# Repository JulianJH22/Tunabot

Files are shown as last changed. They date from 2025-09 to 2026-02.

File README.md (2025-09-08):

# Tunabot
Tunabot es un proyecto educativo y experimental que busca recrear el movimiento y comportamiento de los atunes en el agua.  🐟 Robot Atún: un prototipo que se desplaza en el agua simulando el movimiento natural del pez.  🐟 Sigueobjetos: un sistema que replica los bancos de atunes, siguiendo el movimiento de otros miembros..

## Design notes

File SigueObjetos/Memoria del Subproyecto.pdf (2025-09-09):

# MEMORIA DEL "SIGUEOBJETOS”

## Proyecto Tunabot

TUNABOT | 1

## Memoria del "SigueObjetos”

## 1. Introducción

El subproyecto SigueObjetos forma parte del proyecto global Tunabot, una iniciativa centrada en la divulgación científica y tecnológica en torno al comportamiento del atún, con un enfoque práctico desde la robótica educativa. El SigueObjetos surgió con el objetivo de mostrar, a través de prototipos robóticos, cómo se comportan los atunes en grupo y cómo su coordinación puede ser interpretada y replicada mediante sensores, actuadores y microcontroladores. En este contexto, el subproyecto se centra en emular la capacidad de seguimiento y reacción grupal que muestran los bancos de atunes.

## 2. Objetivo del subproyecto

El objetivo principal es desarrollar un robot capaz de detectar y seguir un objeto, simulando así el comportamiento de los atunes al moverse de forma sincronizada dentro de un banco.
El enfoque del proyecto es tanto divulgativo como formativo, permitiendo a estudiantes y público general explorar principios básicos de sensorización, programación y control robótico.

## 3. Enfoque técnico

### 3.1. Primera fase: SigueColores

La primera versión del prototipo se basó en el concepto de SigueColores. La idea era que el robot fuera capaz de:
- Detectar el color de una tarjeta mediante un sensor RGB.
- Medir la distancia hasta la tarjeta usando un sensor de ultrasonido.
- Detectar el movimiento lateral de la tarjeta mediante dos sensores IR (infrarrojos), ubicados a izquierda y derecha del robot.
- En función de esa información, el robot podría girar a izquierda o derecha o avanzar para seguir la tarjeta.
Componentes utilizados
- Placa Arduino Uno
- Dos motores DC con ruedas (movimiento)
- Sensor RGB (detección de color)
- Sensor ultrasónico HC-SR04 (medición de distancia)
- Dos sensores infrarrojos (detección de movimiento lateral)

- Chasis básico de robot con soporte para los componentes
- Batería o alimentación externa

### 3.1.1. Desarrollo del prototipo

El desarrollo se dividió en varias etapas:
1. Montaje físico del robot: Ensamblaje del chasis, motores, sensores y cableado con la placa Arduino.
2. Programación de sensores:
- Se calibró el sensor RGB para reconocer únicamente el color deseado de la tarjeta.
- Se establecieron umbrales de distancia segura con el sensor ultrasónico.
- Se configuraron los sensores IR para detectar si el objeto se desplazaba a un lado u otro.
3. Lógica de movimiento:
- Si el objeto está centrado y dentro del rango de distancia, el robot avanza.
- Si el objeto se desplaza hacia un lateral, el robot gira hacia ese lado.
- Si se pierde el objeto o se aleja demasiado, el robot se detiene.
- En cada paso se deberá confirmar que el color de la tarjeta es el deseado.
4. Pruebas y ajustes: Se realizaron pruebas en distintos entornos y condiciones de luz, adaptando parámetros para mejorar la estabilidad y precisión.

### 3.1.2. Resultados y dificultades

El robot era capaz de identificar la tarjeta y perseguirla, pero solo bajo unas condiciones lumínicas específicas que dependía tanto de la iluminación interior como del clima y la hora del día.

### 3.1.3. Conclusiones y mejoras futuras

Debido a los resultados obtenidos y a la fuerte dependencia del robot de la luz, se decidió tomar otra orientación en el proyecto y hacerlo SigueObjetos. De esta forma se elimina la dependencia de la luz, pues no habría colores que determinar y además se simplificaría significativamente, ideal para la divulgación.

### 3.2. Segunda fase: SigueObjetos

La segunda versión del prototipo se basó en el concepto de SigueObjetos. La idea era que el robot fuera capaz de:
- Medir la distancia hasta un objeto usando un sensor de ultrasonido.
- Detectar el movimiento lateral de la tarjeta mediante dos sensores ultrasonido, ubicados a izquierda y derecha del robot.
- En función de esa información, el robot podría girar a izquierda o derecha o avanzar para seguir la tarjeta.
Componentes utilizados
- Placa Arduino Uno
- Dos motores DC con ruedas (movimiento)
- Tres Sensores ultrasónicos HC-SR04 (medición de distancia)
- Chasis básico de robot con soporte para los componentes
- Batería o alimentación externa

### 3.2.1. Desarrollo del prototipo

El desarrollo se dividió en varias etapas:
5. Montaje físico del robot: Ensamblaje del chasis, motores, sensores y cableado con la placa Arduino.
6. Programación de sensores:
- Se establecieron umbrales de distancia segura con el sensor ultrasónico frontal.
- Se configuraron los sensores ultrasónicos laterales para detectar si el objeto se desplazaba a un lado u otro. Para facilitar su uso se digitalizaron (darían un 1 si la distancia era menor a la determinada en programación y 0 si era mayor).
7. Lógica de movimiento:
- Si el objeto está centrado y dentro del rango de distancia, el robot avanza.
- Si el objeto se desplaza hacia un lateral, el robot gira hacia ese lado.
- Si se pierde el objeto o se aleja demasiado, el robot se detiene.
8. Pruebas y ajustes: Se realizaron pruebas en distintos entornos, adaptando parámetros para mejorar la estabilidad y precisión.

### 3.2.2. Resultados y dificultades

El robot era capaz de perseguir el objeto sin problemas aparentes, tras pulir el código y los parámetros no hubo problemas en el desempeño del robot.

### 3.2.3. Conclusiones y mejoras futuras

Debido al éxito en el desarrollo de este robot se decidió hacerlo más estético diseñando una PCB (Printed Circuit Board) para simplificar las conexiones y un carenado en forma de atún.

## 4. Anexo de Imágenes

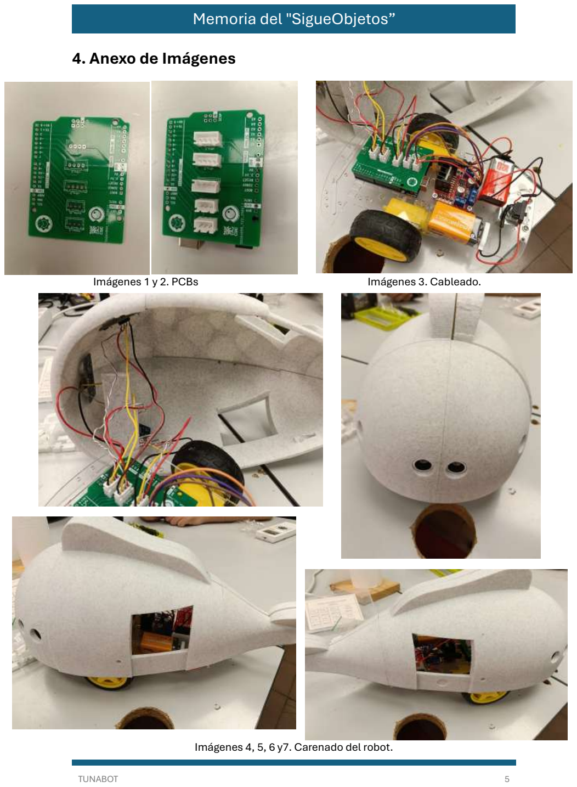
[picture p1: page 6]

Imágenes 1 y 2. PCBs | Imágenes 3. Cableado.

Imágenes 4, 5, 6 y7. Carenado del robot.

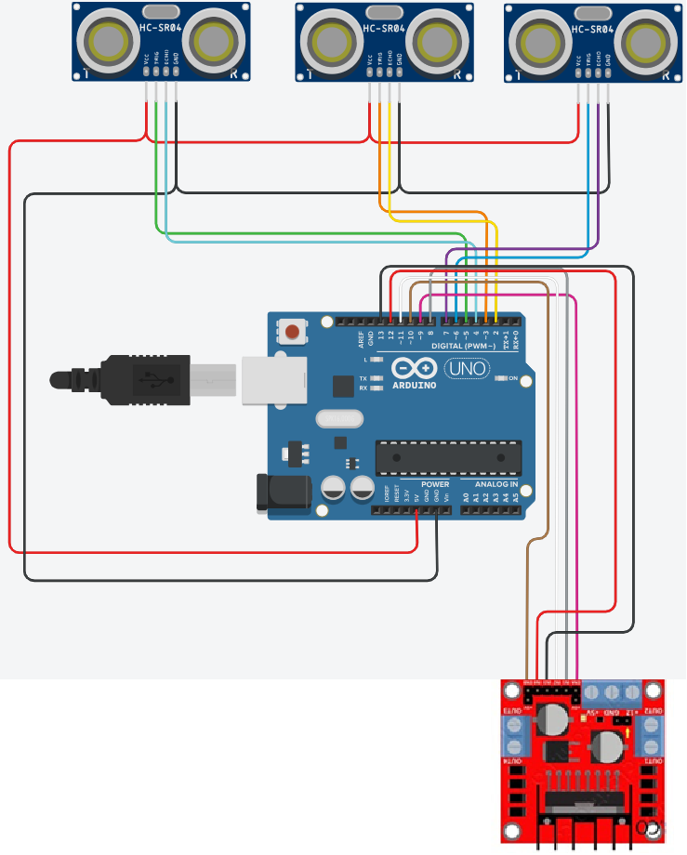
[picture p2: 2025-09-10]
SigueObjetos/Esquemático.png

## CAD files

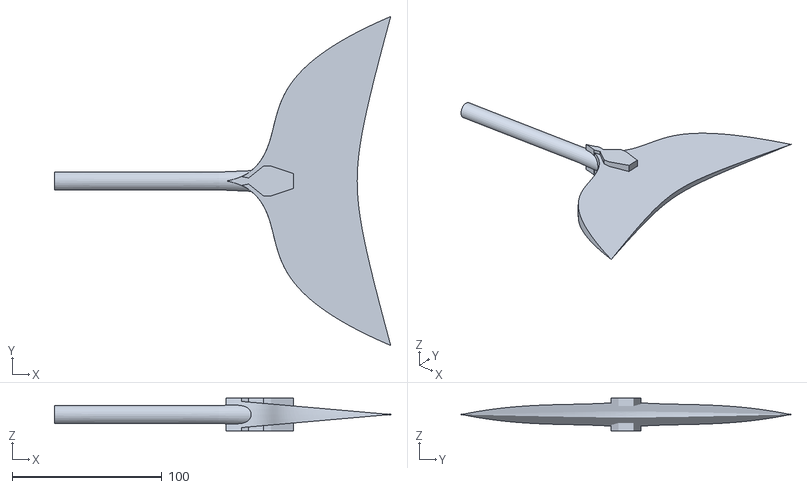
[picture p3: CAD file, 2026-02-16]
RobotAtun/Cola.stl
225.0 x 220.0 x 22.0

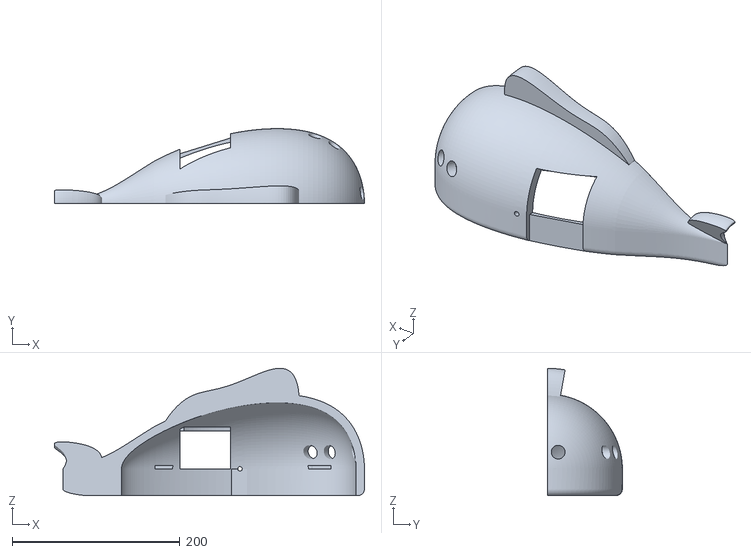
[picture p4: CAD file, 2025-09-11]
SigueObjetos/STL/PezSiemtrico.stl
370.0 x 89.2 x 152.0

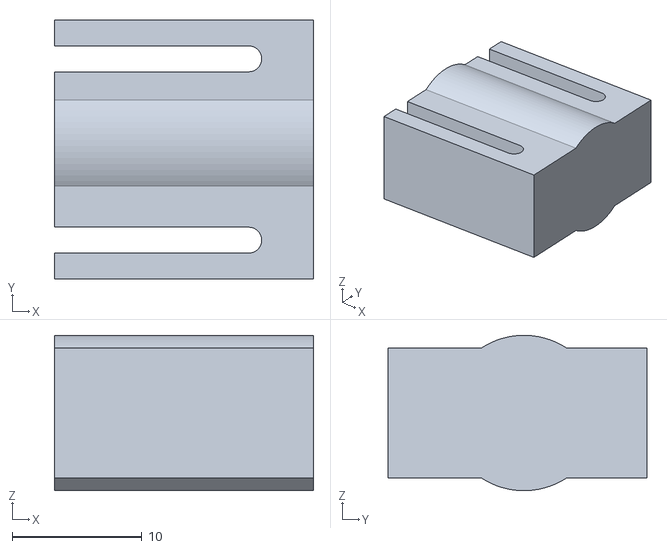
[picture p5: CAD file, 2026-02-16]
RobotAtun/Soporte_Transmision.stl
20.0 x 20.0 x 12.0

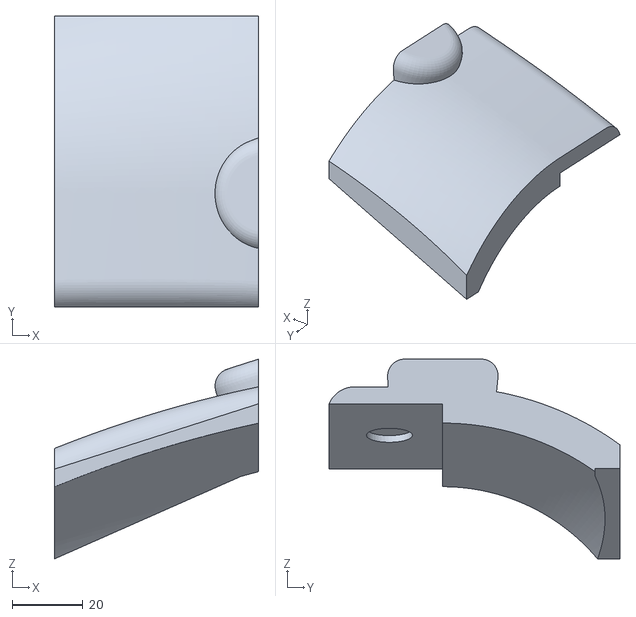
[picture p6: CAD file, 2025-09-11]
SigueObjetos/STL/PuertaDer.stl
57.5 x 82.0 x 56.3

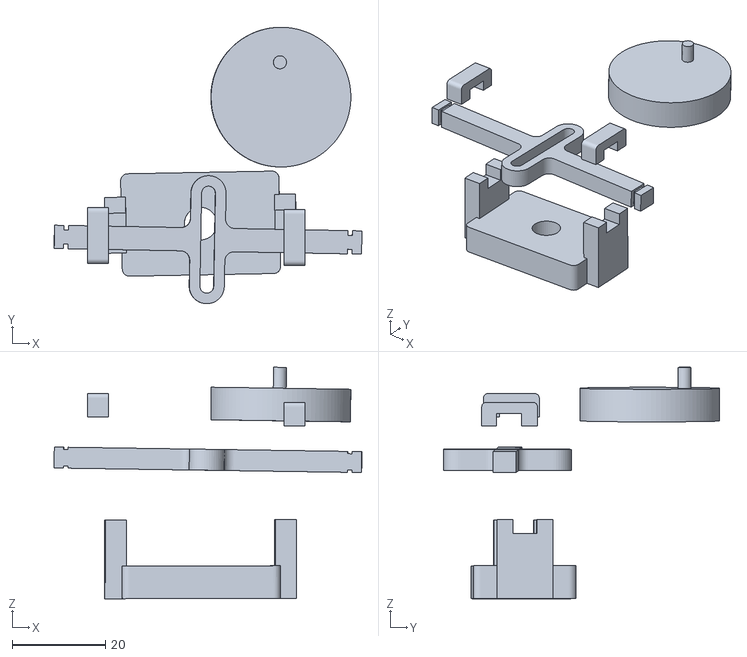
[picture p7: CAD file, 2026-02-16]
RobotAtun/yugo reforzado.stl
66.1 x 59.4 x 49.7

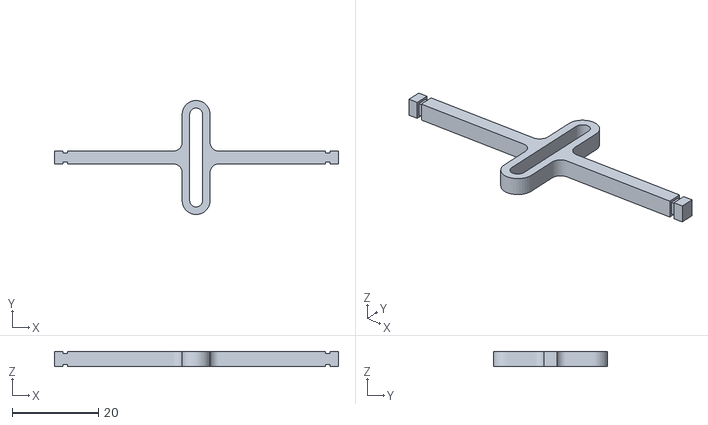
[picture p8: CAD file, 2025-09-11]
SigueObjetos/STL/YugoYE.stl
66.0 x 26.5 x 3.50

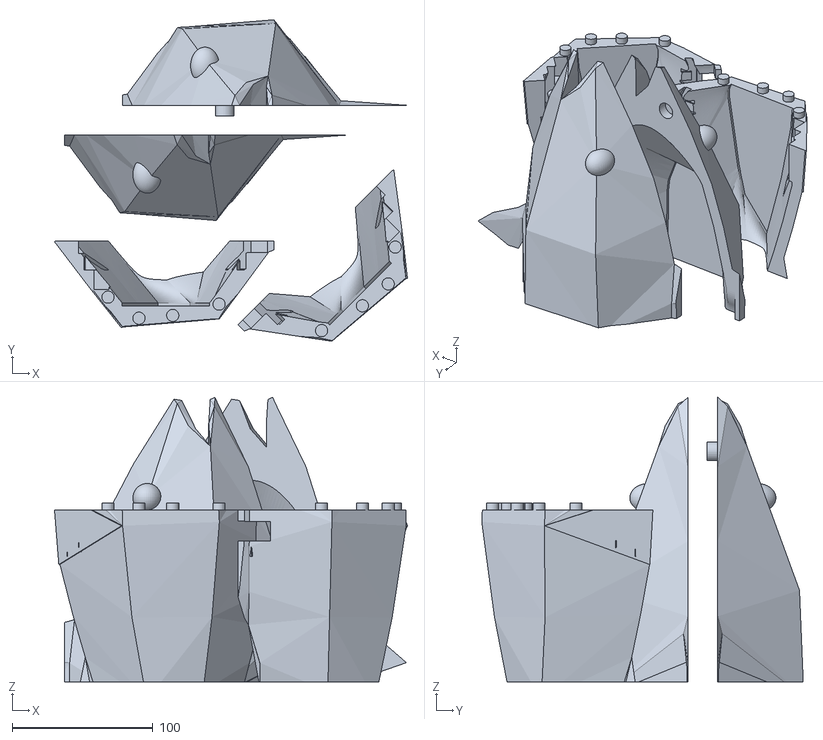
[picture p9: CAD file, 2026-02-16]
RobotAtun/Carcasa.stl
251.1 x 228.6 x 202.3

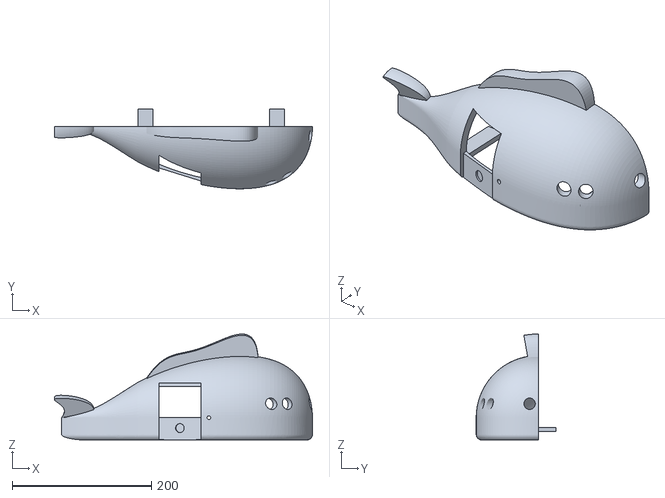
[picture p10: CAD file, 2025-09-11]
SigueObjetos/STL/Pez_Mejoradp.stl
370.0 x 114.2 x 152.0

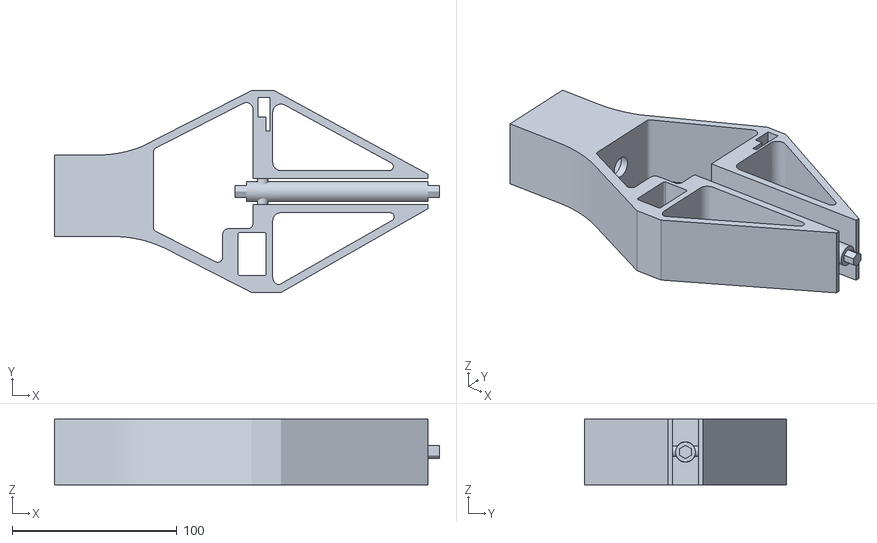
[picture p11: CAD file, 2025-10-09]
RobotAtun/Esqueleto_Atún.stl
233.4 x 122.4 x 40.0

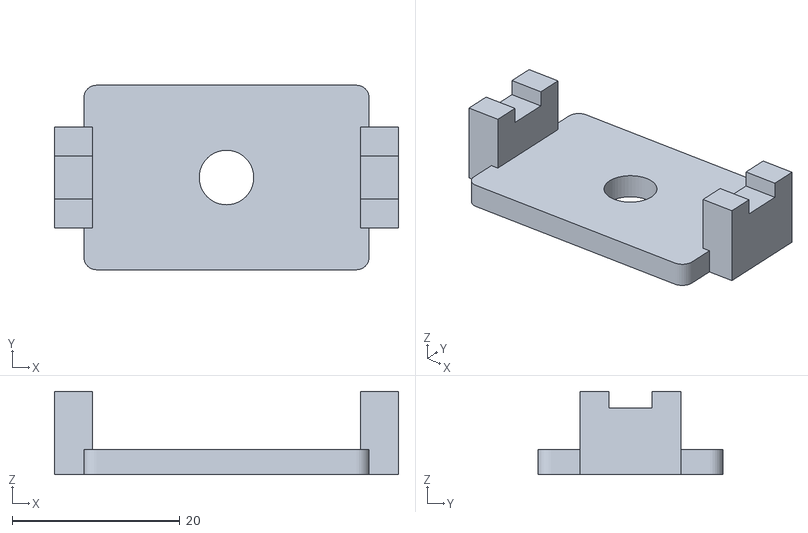
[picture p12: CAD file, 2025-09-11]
SigueObjetos/STL/Yugo1.stl
41.0 x 22.0 x 9.92

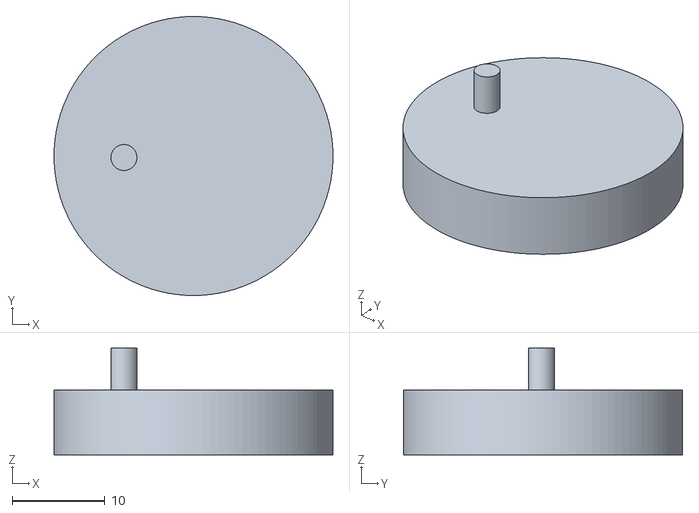
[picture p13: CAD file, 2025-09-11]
SigueObjetos/STL/Yugo2.stl
30.0 x 30.0 x 11.5

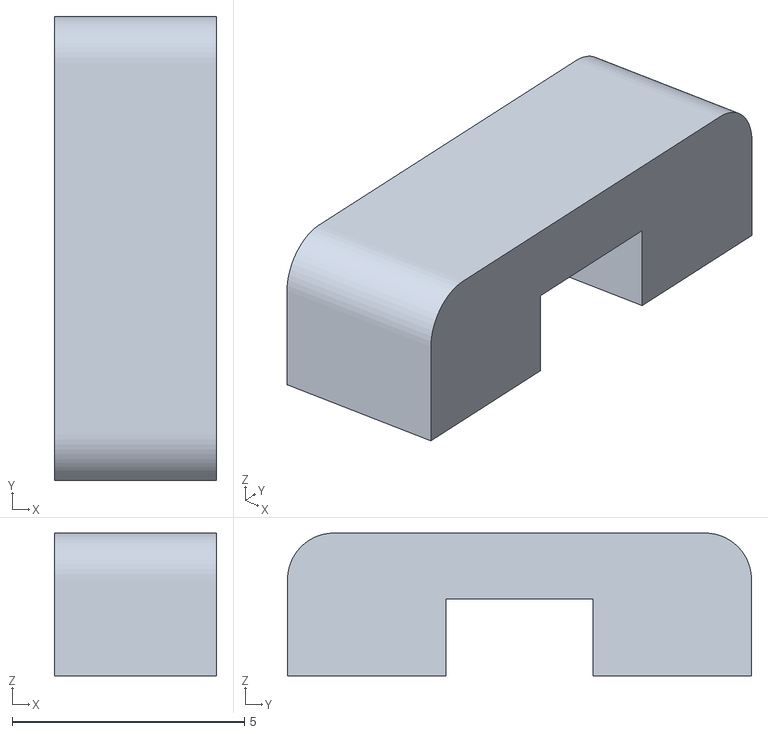
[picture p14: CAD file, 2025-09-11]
SigueObjetos/STL/TapaYE.stl
3.50 x 10.0 x 3.08

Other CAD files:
SigueObjetos/STL/PuertaIzq.stl
SigueObjetos/Fusion/Pez 5 v1.f3d
SigueObjetos/Fusion/Puerta pez 5.0 v1 (1).f3d
SigueObjetos/Fusion/yugo reforzado (2) (2).f3d

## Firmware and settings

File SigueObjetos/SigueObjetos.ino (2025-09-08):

#include <Wire.h>

const int TrigC=3;
const int EchC=2;

const int TrigI=5;
const int EchI=4;

const int TrigD=6;
const int EchD=7;

const int MDF=8;
const int MDB=11;
const int MDENB=9;

const int MIF=12;
const int MIB=13;
const int MIENB=10;

/*
Suponiendo Arduino UNO

-----Conexión Ultrasonidos-----
    Echo-2                      Trigger-3
    VIN-5V                      
    GND-GND

    Echo-4                      Trigger-5
    VIN-5V                      
    GND-GND

    Echo-6                      Trigger-7
    VIN-5V                      
    GND-GND

-----Conexión Motores-----
    Derecho (Puente H)
    Movimiento hacia adelante-8        Movimiento hacia atrás-11
    ENB-9

    Izquierdo (Puente H)
    Movimiento hacia adelante-12        Movimiento hacia atrás-13
    ENB-10
*/
long dist(int trigger, int echo);
void girarDerecha();
void girarIzquierda();
void Avanti();
void Stop();

void setup() {
  // put your setup code here, to run once:
  //Esta secuencia es para checkear que funciona el módulo de color.
  Serial.begin(9600);


  //Configurar los ultrasonidos.
  pinMode(TrigC, OUTPUT);
  pinMode(EchC, INPUT);

  pinMode(TrigI, OUTPUT);
  pinMode(EchI, INPUT);

  pinMode(TrigD, OUTPUT);
  pinMode(EchD, INPUT);


  //Configurar motores.
  pinMode(MDF, OUTPUT);
  pinMode(MDB, OUTPUT);
  pinMode(MDENB, OUTPUT);

  digitalWrite(MDF, HIGH);
  digitalWrite(MDB, LOW);

  pinMode(MIF, OUTPUT);
  pinMode(MIB, OUTPUT);
  pinMode(MIENB, OUTPUT);

  digitalWrite(MIF, HIGH);
  digitalWrite(MIB, LOW);

}

void loop() {
  // put your main code here, to run repeatedly:
  //Calculamos las distancias de los ultrasonidos.
  long dC, dI, dD;
  dC = dist(TrigC, EchC);
  dI = dist(TrigI, EchI);
  dD = dist(TrigD, EchD);
  Serial.print("DistC: ");
  Serial.println(dC);
  Serial.print("DistD: ");
  Serial.println(dD);
  Serial.print("DistI: ");
  Serial.println(dI);

  //¿Es el color correcto?
  if (dC >= 5 && dC < 15){
      //Motores hacia adelante
      Avanti();
      Serial.println("Av");
    }else if(dC < 5){
      Stop();
      Serial.println("ST");
    }else if (dD < 10){
      //Giro derecha
      girarDerecha(150);
      Serial.println("Der");
    } else if (dI < 10){
      //Giro izquierda
      girarIzquierda(150);
      Serial.println("Izq");
    } else{
     /*do{
      girarDerecha(100);
      Serial.println("Derer");
      dC = dist(TrigC, EchC);
      dI = dist(TrigI, EchI);
      dD = dist(TrigD, EchD);
      }while(!(dC < 10 || dI < 5 || dD < 5));*/
      Stop();
    }
}

long dist(int trigger, int echo){
  long t;
  long d;
  digitalWrite(trigger, HIGH);
  delayMicroseconds(10);
  digitalWrite(trigger, LOW);
  t = pulseIn(echo, HIGH);
  d = 0.0172*t;
  return d;
}

void girarDerecha(int V){
  digitalWrite(MDF, LOW);
  digitalWrite(MDB, HIGH);
  digitalWrite(MIF, HIGH);
  digitalWrite(MIB, LOW);
  analogWrite(MDENB, V);
  analogWrite(MIENB, V);
}

void girarIzquierda(int V){
  digitalWrite(MDF, HIGH);
  digitalWrite(MDB, LOW);
  digitalWrite(MIF, LOW);
  digitalWrite(MIB, HIGH);
  analogWrite(MDENB, V);
  analogWrite(MIENB, V);
}

void Avanti(){
  digitalWrite(MDF, HIGH);
  digitalWrite(MDB, LOW);
  digitalWrite(MIF, HIGH);
  digitalWrite(MIB, LOW);
  analogWrite(MDENB, 250);
  analogWrite(MIENB, 250);
}
void Stop(){
  digitalWrite(MDF, HIGH);
  digitalWrite(MDB, LOW);
  digitalWrite(MIF, HIGH);
  digitalWrite(MIB, LOW);
  analogWrite(MDENB, 0);
  analogWrite(MIENB, 0);
}

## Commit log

2025-10-09 upload stl esqueleto
    [Esqueleto_Atún.stl]
2026-02-16 Archivos robot atun
    [Carcasa.stl, Cola.stl, Soporte_Transmision.stl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]
